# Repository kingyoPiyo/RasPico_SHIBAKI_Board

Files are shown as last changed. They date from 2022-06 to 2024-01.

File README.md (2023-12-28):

# RasPico_SHIBAKI_Board
Raspberry Pi Pico で色々やる基板です。  

### 搭載インタフェース
| インタフェース | 説明 |
| ---- | ---- |
| SFP | 2スロット搭載。TXRX、LOS、TX_FAULT、I2C の基本的な信号線が Pico と接続されています。RATE_SELECT、TX_DISABLE ははんだジャンパで指定します。 |
| GPIO | 2.54mm pitch 2x5ピンヘッダを搭載。4pin + 3.3V + GND が出ています。機能拡張等に使用できます。 |
| LED | 4個搭載（Pico ボードに標準搭載のLEDを含めると合計5個）。Lチカデバッグや UART、S/PDIF 信号を出力して遊べます。 |
| Push SW | User 用2個（プルアップ抵抗付き）、Reset 用1個搭載 |
| SMA Input | 2個搭載。50Ω終端抵抗（標準では未実装）を実装するパッドを用意しています。 |
| SMA Output | 2個搭載。標準で 450Ω の抵抗が直列に挿入されています。50Ω 終端可能なオシロスコープに接続するとx10減衰として機能します。レベルを変更したい場合は適宜抵抗を打ち替えてください。 |

### 基板画像
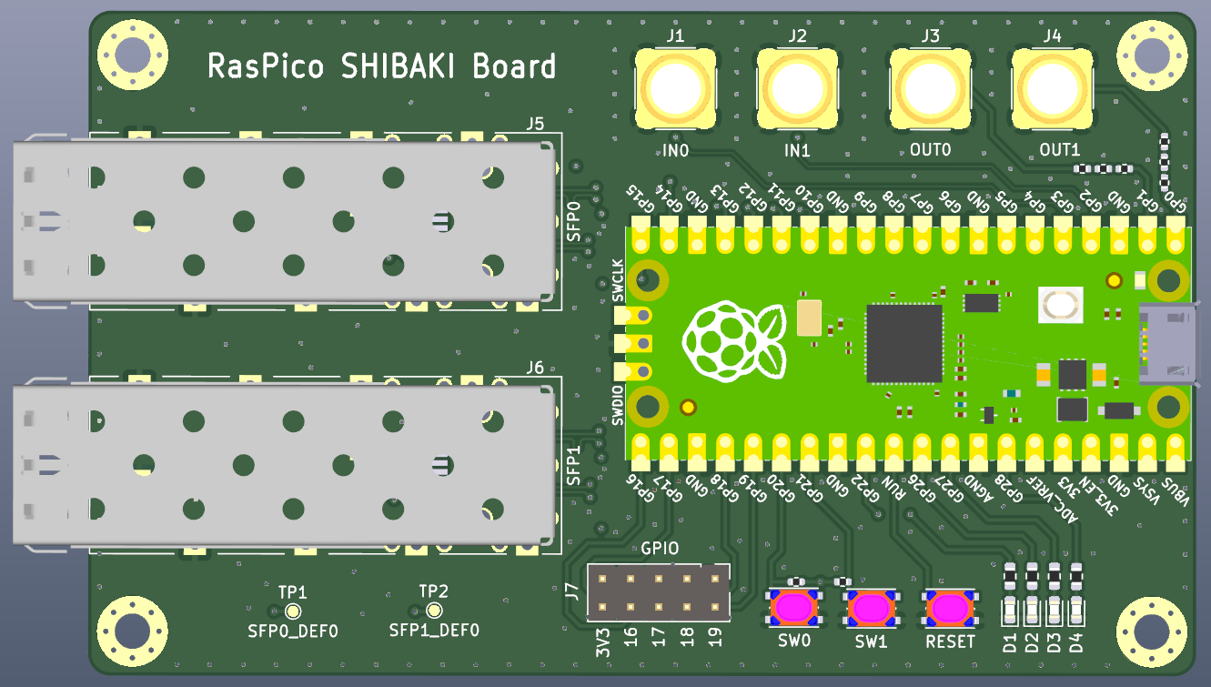
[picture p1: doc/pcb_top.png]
  
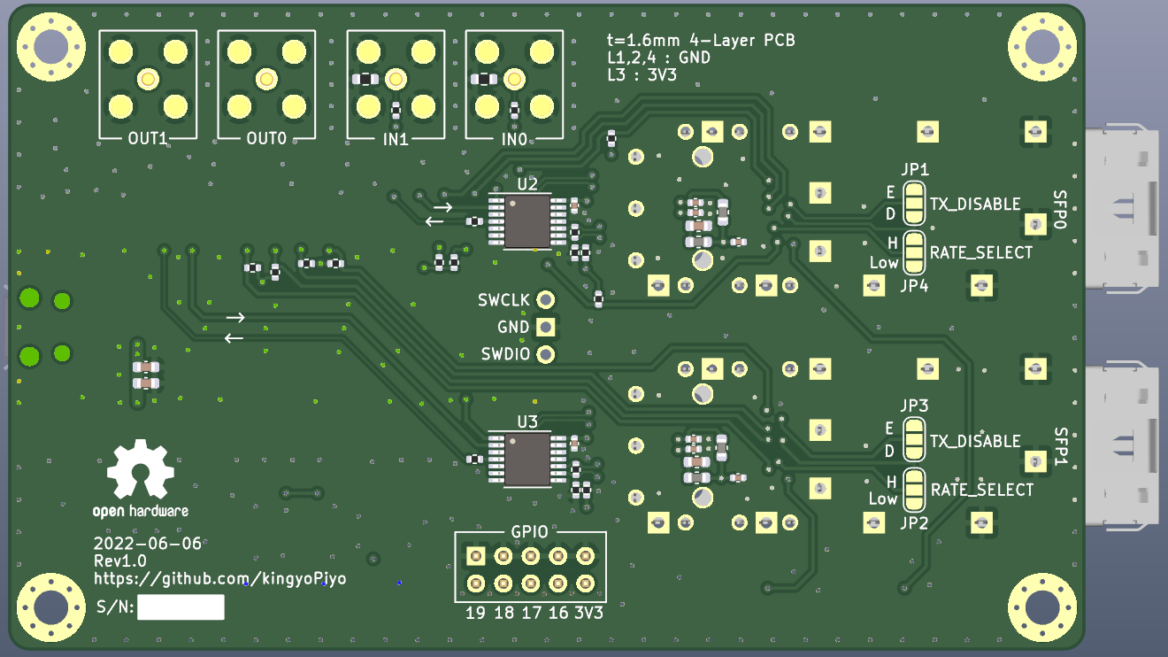
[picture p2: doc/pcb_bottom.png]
  
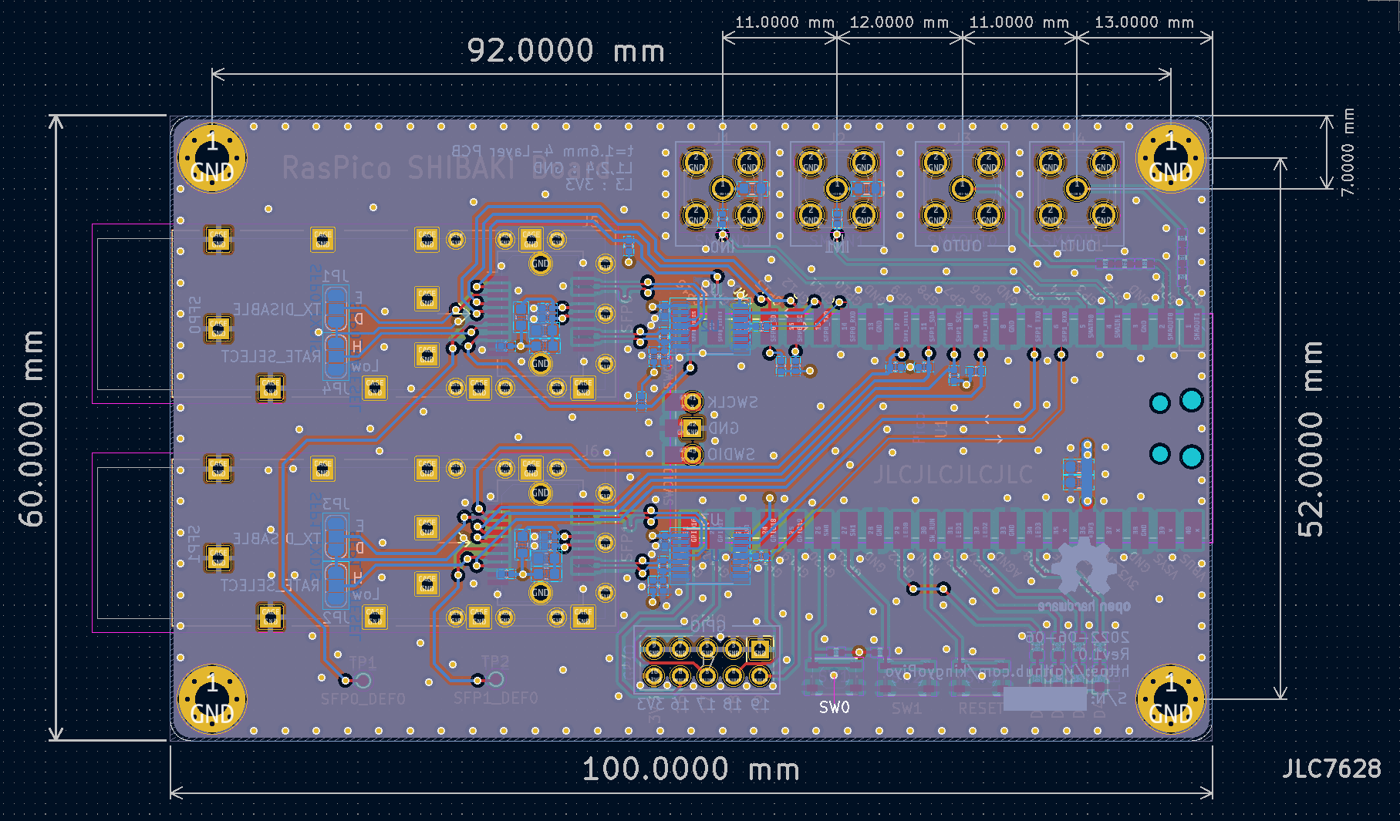
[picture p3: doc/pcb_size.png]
  
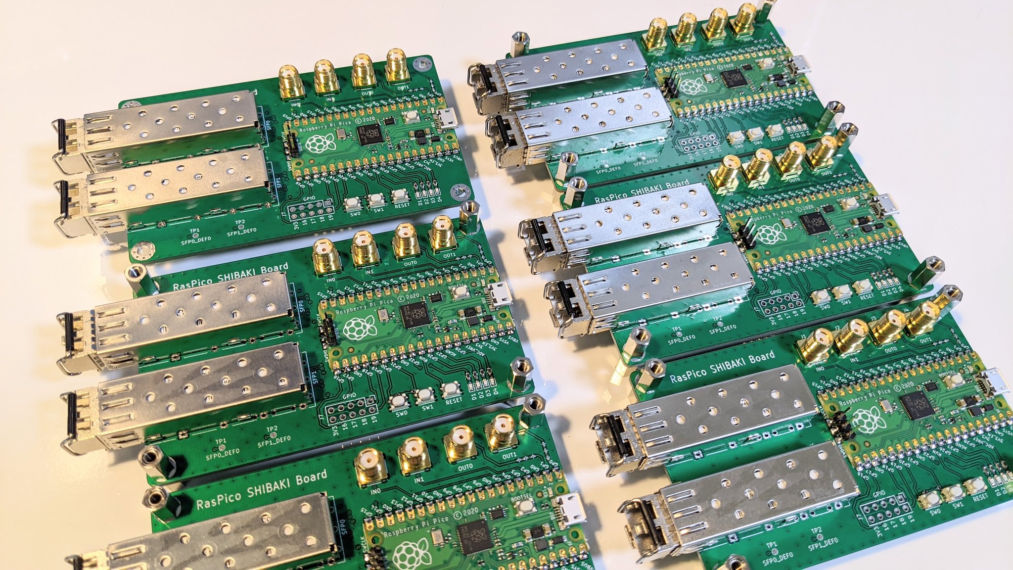
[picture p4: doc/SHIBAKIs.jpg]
  

## サンプルソフトウェア
本ボードで遊べるサンプルプログラムです。  
100BASE-FX による UDP 送信例、VBAN プロトコルによる PCM データ送信、SFP モジュール情報読み出し、8b10b エンコード・デコード（PIO を使った SerDes with Clockrecovery）等を追々追加していく予定です。  
| Link | 説明 |
| ---- | ---- |
| [hwtest](firmware/hwtest/ "hwtest") | ハードウェアテスト用。<br> リセット直後にUSBシリアルから各ピンの電圧レベルやSFPモジュールのI2C読み出しデータ（Addr 0x50）等が出力されます。SW0押下でSFP0ポートからUDPパケットを100BASE-FXでブロードキャストします。SFP1の送受信は実装中... |
| [vban](firmware/vban/ "vban") | RasPico ADC + VBAN Protocol サンプル。<br> GP26(ADC0), GP27(ADC1) からオーディオ信号を入力すると、方チャンネル44.1kHzでサンプリングされてVBANプロトコルに載せてストリーミング送信します。ネットワーク設定はudp.hを適宜書き換えてください。 |
| [pattern_gen](firmware/pattern_gen/ "pattern_gen") | PIOを活用したパターンジェネレータサンプル。<br> SFP0とSMAOUT0端子から125MS/sで位相同期した任意のパターンを出力します。<br> SFPモジュールの伝搬遅延の評価等に使えます。サンプリングクロック周波数や出力端子も任意に設定可能です。 |

## 回路図
[Schematic.pdf](doc/schematic.pdf "Schematic")

## 既知のバグ
[doc/Rev1.0_Jumper.png](doc/Rev1.0_Jumper.png "Rev1.0_Jumper.png") 参照
* SFP0_SCLとSFP0_SDAのピンアサインを入れ替える必要あり
* SFP1_SCLがI2C1_SCLに、SFP1_SDAがI2C0_SDAに割りあたっており、配線修正必要

## 開発環境
- KiCad Version 6.0.5
- Raspberry Pi Pico 3D model and Footprint : [KiCad-RP-Pico](https://github.com/ncarandini/KiCad-RP-Pico "KiCad-RP-Pico")

## pico-sdk install memo
```
sudo apt install cmake gcc-arm-none-eabi libnewlib-arm-none-eabi libstdc++-arm-none-eabi-newlib build-essential
git clone https://github.com/raspberrypi/pico-sdk
cd pico-sdk
git submodule update --init
```

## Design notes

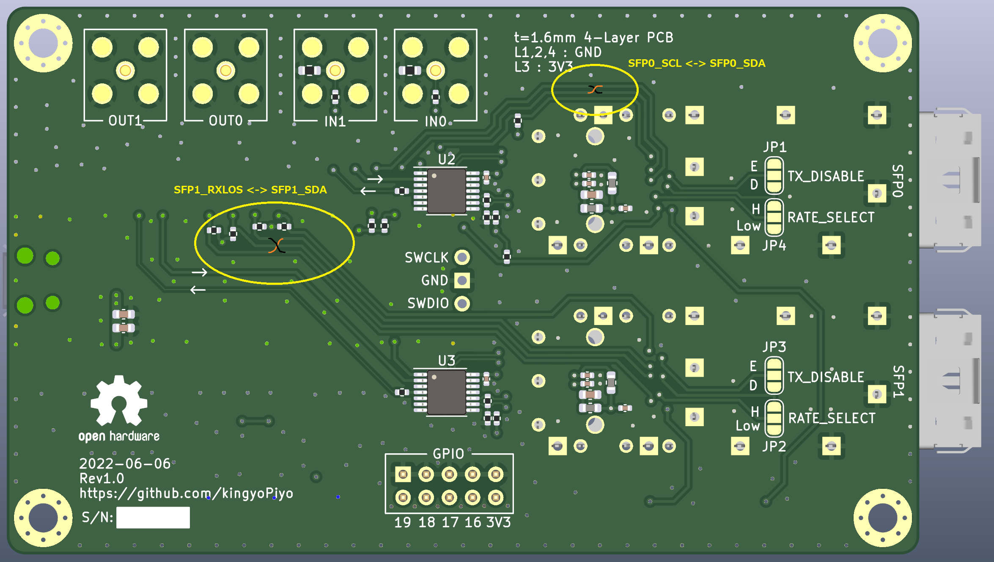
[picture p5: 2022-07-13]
doc/Rev1.0_Jumper.png

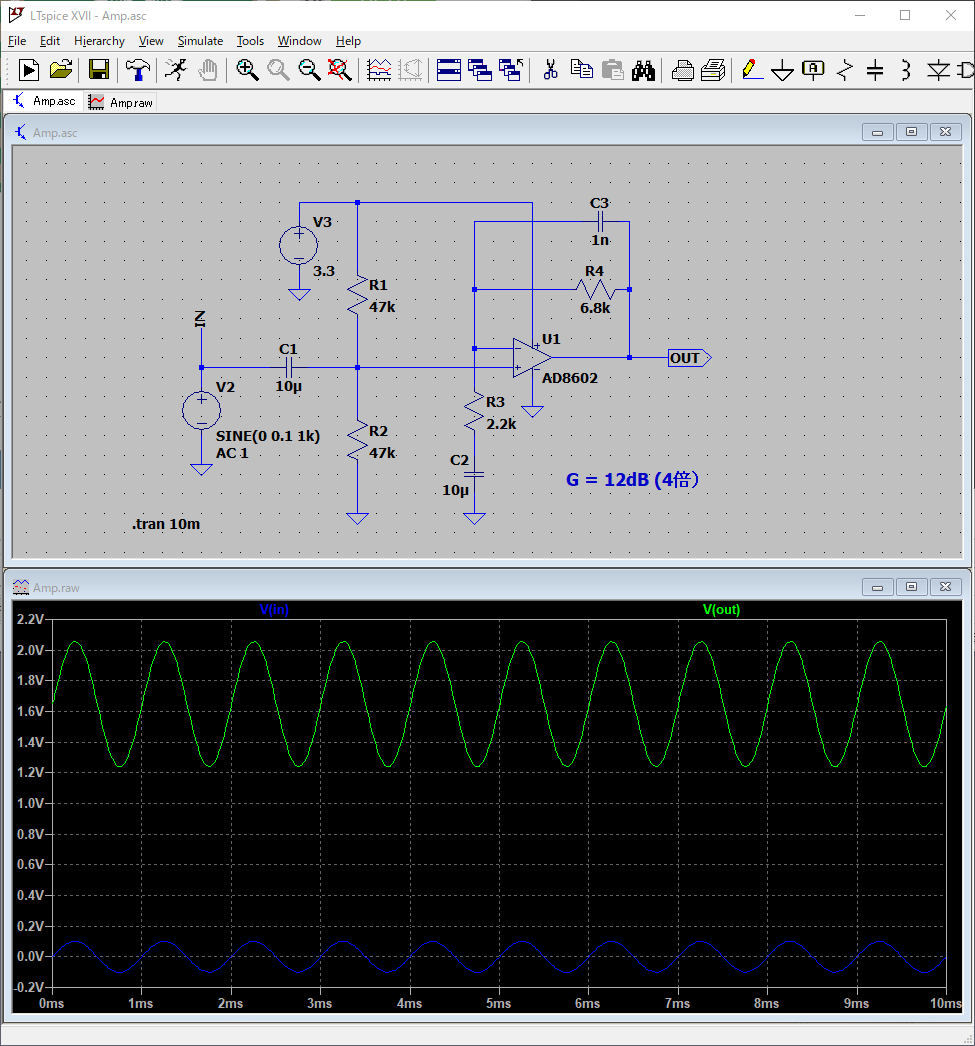
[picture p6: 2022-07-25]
firmware/vban/doc/ADC_PreAmp.png

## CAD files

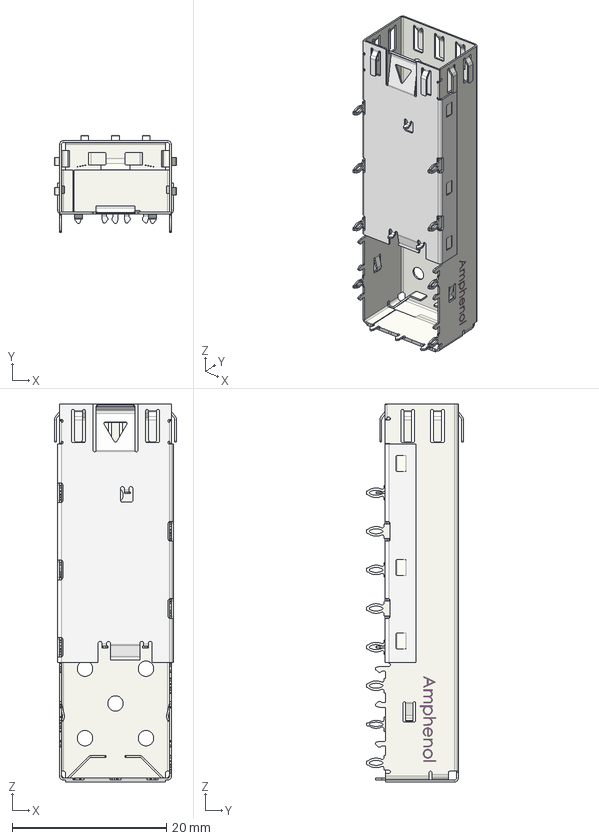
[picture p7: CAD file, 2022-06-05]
KiCad/3D/M-U77-A1118-X00X-REVG5.step
15.8 x 12.6 x 49.0 mm

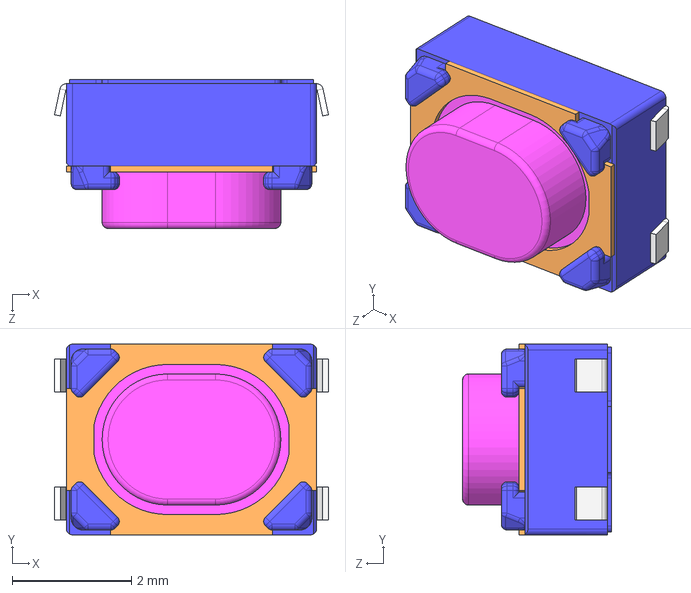
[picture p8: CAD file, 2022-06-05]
KiCad/3D/SKRPAB.STEP
4.60 x 3.20 x 2.50 mm

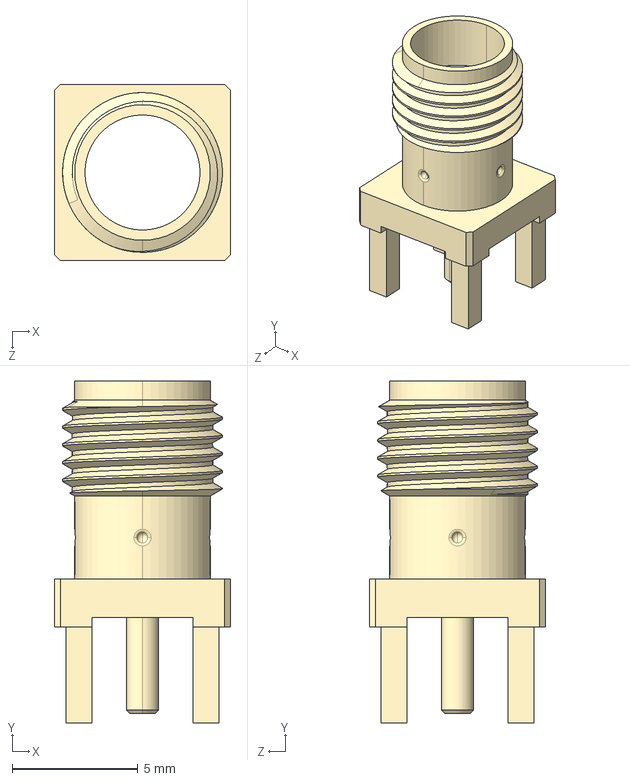
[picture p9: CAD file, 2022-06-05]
KiCad/3D/CONSMA001-G--3DModel-STEP-1.STEP
7.01 x 13.6 x 7.01 mm

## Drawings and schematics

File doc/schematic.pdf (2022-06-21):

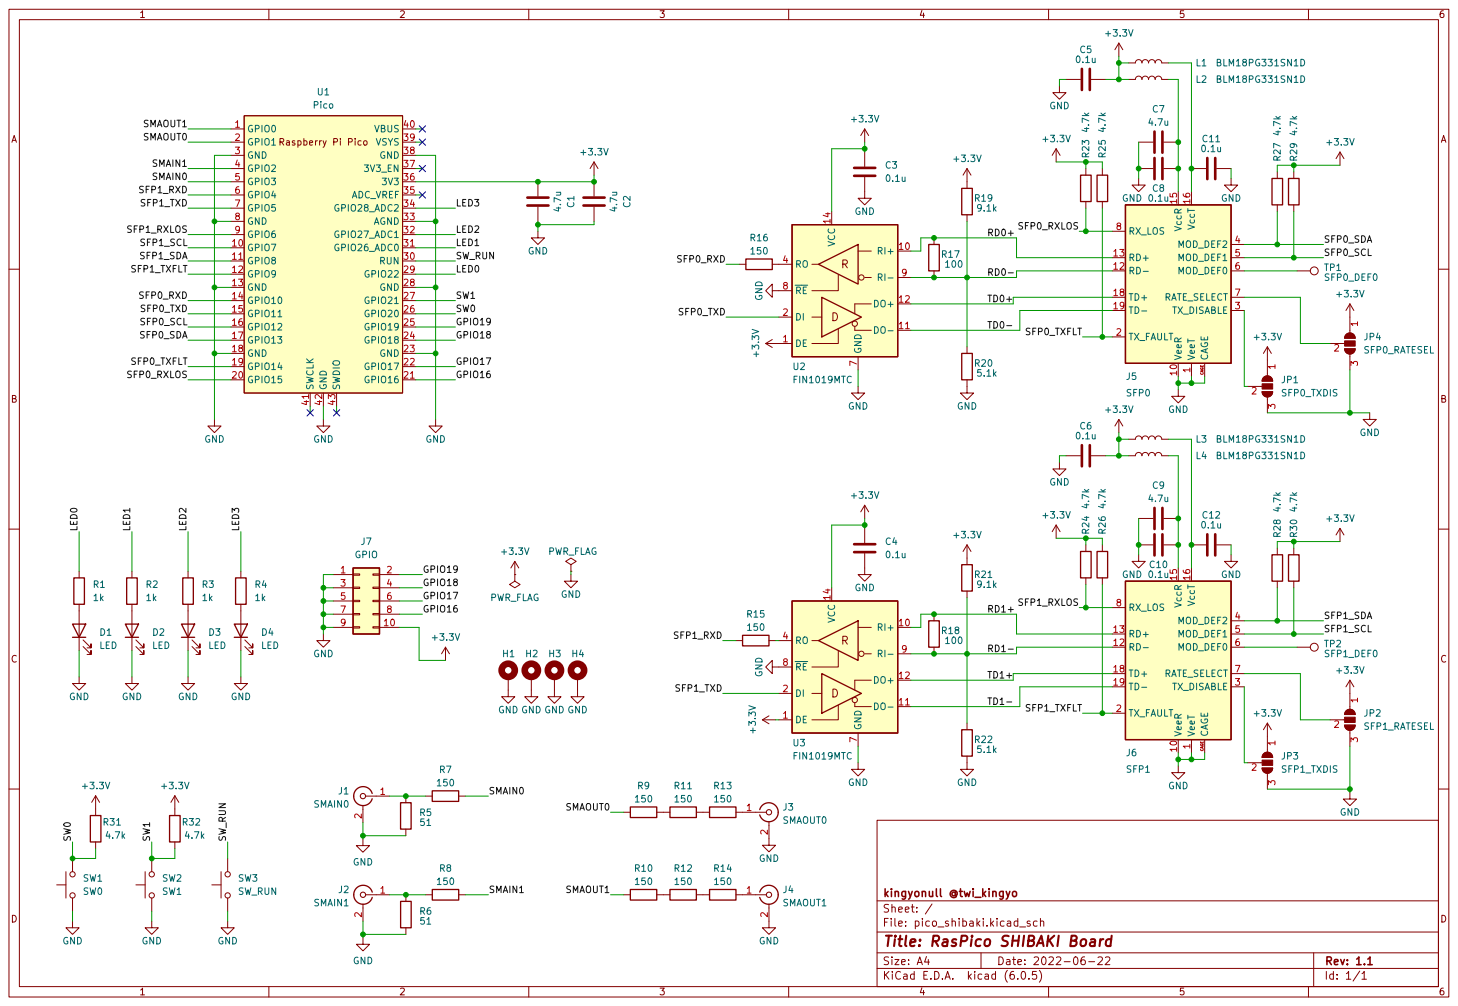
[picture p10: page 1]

1 VeeR 10 RD- 12 RD+ 13 VccR 15 VccT 16 TD+ 18 TD- 19 TX_FAULT 2 TX_DISABLE 3 MOD_DEF2 4 MOD_DEF1 5 MOD_DEF0 6 RATE_SELECT 7 RX_LOS 8 CAGE CAGE J5SFP0 +3.3V GND

7 ~{RE} 8 RI- 9 U2FIN1019MTC GND +3.3V GND VeeT

1 VeeR 10 RD- 12 RD+ 13 VccR 15 VccT 16 TD+ 18 TD- 19 TX_FAULT 2 TX_DISABLE 3 MOD_DEF2 4 MOD_DEF1 5 MOD_DEF0 6 RATE_SELECT 7 RX_LOS 8 CAGE CAGE J6SFP1 +3.3V GND

Id: 1/1 Title: RasPico SHIBAKI Board

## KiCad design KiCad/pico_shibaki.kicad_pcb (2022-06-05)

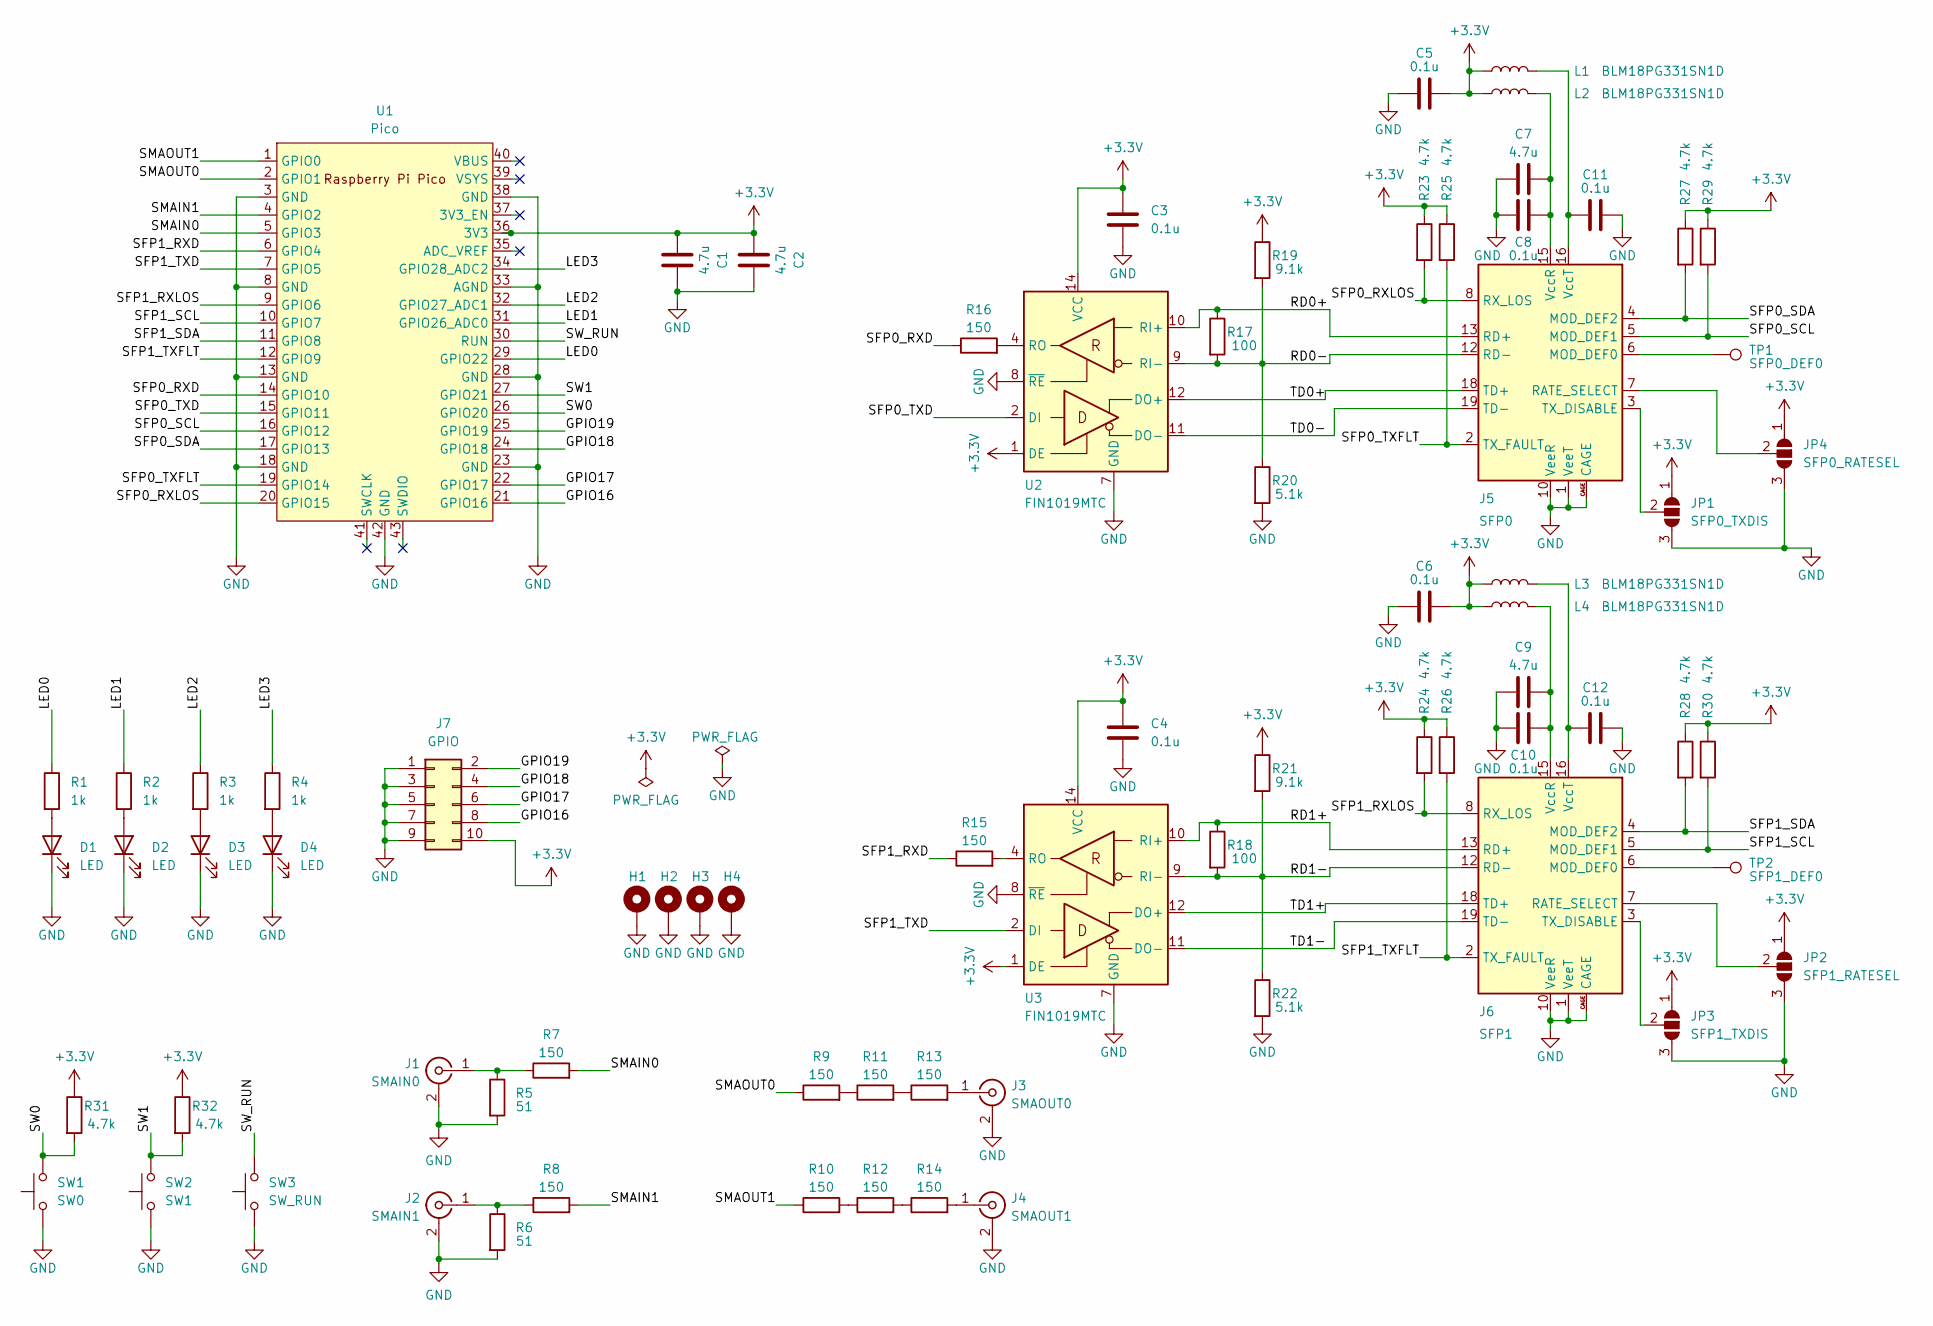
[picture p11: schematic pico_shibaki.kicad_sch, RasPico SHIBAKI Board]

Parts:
C1, C2, C7, C9: 4.7u; C_0603_1608Metric
C3, C4, C5, C6, C8, C10, C11, C12: 0.1u; C_0402_1005Metric
D1, D2, D3, D4: LED; LED_0603_1608Metric
H1, H2, H3, H4: MountingHole_Pad; MountingHole_3.2mm_M3_Pad_Via
J1: SMAIN0; SMA_Amphenol_132134_Vertical
J2: SMAIN1; SMA_Amphenol_132134_Vertical
J3: SMAOUT0; SMA_Amphenol_132134_Vertical
J4: SMAOUT1; SMA_Amphenol_132134_Vertical
J5: SFP0; Connector_SFP_and_Cage
J6: SFP1; Connector_SFP_and_Cage
J7: GPIO; PinHeader_2x05_P2.54mm_Vertical
JP1: SFP0_TXDIS; SolderJumper-3_P1.3mm_Open_RoundedPad1.0x1.5mm_NumberLabels
JP2: SFP1_RATESEL; SolderJumper-3_P1.3mm_Open_RoundedPad1.0x1.5mm_NumberLabels
JP3: SFP1_TXDIS; SolderJumper-3_P1.3mm_Open_RoundedPad1.0x1.5mm_NumberLabels
JP4: SFP0_RATESEL; SolderJumper-3_P1.3mm_Open_RoundedPad1.0x1.5mm_NumberLabels
L1, L2, L3, L4: BLM18PG331SN1D; L_0603_1608Metric
R1, R2, R3, R4: 1k; R_0603_1608Metric
R5, R6: 51; R_0603_1608Metric
R7, R8, R9, R10, R11, R12, R13, R14, R15, R16: 150; R_0402_1005Metric
R17, R18: 100; R_0402_1005Metric
R19, R21: 9.1k; R_0402_1005Metric
R20, R22: 5.1k; R_0402_1005Metric
R23, R24, R25, R26, R27, R28, R29, R30, R31, R32: 4.7k; R_0402_1005Metric
SW1: SW0; SW_Push_1P1T_NO_Vertical_Wuerth_434133025816
SW2: SW1; SW_Push_1P1T_NO_Vertical_Wuerth_434133025816
SW3: SW_RUN; SW_Push_1P1T_NO_Vertical_Wuerth_434133025816
TP1: SFP0_DEF0; TestPoint_Pad_D1.0mm
TP2: SFP1_DEF0; TestPoint_Pad_D1.0mm
U1: Pico; RPi_Pico_SMD_TH
U2, U3: FIN1019MTC; TSSOP-14_4.4x5mm_P0.65mm

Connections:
+3V3: C1.1, C2.1, C3.1, C4.1, C5.2, C6.2, J7.10, JP1.1 (A), JP2.1 (A), JP3.1 (A), JP4.1 (A), L1.1, L2.1, L3.1, L4.1, R19.1, R21.1, R23.1, R24.1, R25.1, R26.1, R27.1, R28.1, R29.1, R30.1, R31.1, R32.1, U1.36 (3V3), U2.1 (DE), U2.14 (VCC), U3.1 (DE), U3.14 (VCC)
/GPIO16: J7.8, U1.21 (GPIO16)
/GPIO17: J7.6, U1.22 (GPIO17)
/GPIO18: J7.4, U1.24 (GPIO18)
/GPIO19: J7.2, U1.25 (GPIO19)
/LED0: R1.1, U1.29 (GPIO22)
/LED1: R2.1, U1.31 (GPIO26_ADC0)
/LED2: R3.1, U1.32 (GPIO27_ADC1)
/LED3: R4.1, U1.34 (GPIO28_ADC2)
/RD0+: J5.13 (RD+), R17.1, U2.10 (RI+)
/RD0-: J5.12 (RD-), R17.2, R19.2, R20.1, U2.9 (RI-)
/RD1+: J6.13 (RD+), R18.1, U3.10 (RI+)
/RD1-: J6.12 (RD-), R18.2, R21.2, R22.1, U3.9 (RI-)
/SFP0_RXD: R16.1, U1.14 (GPIO10)
/SFP0_RXLOS: J5.8 (RX_LOS), R23.2, U1.20 (GPIO15)
/SFP0_SCL: J5.5 (MOD_DEF1), R29.2, U1.16 (GPIO12)
/SFP0_SDA: J5.4 (MOD_DEF2), R27.2, U1.17 (GPIO13)
/SFP0_TXD: U1.15 (GPIO11), U2.2 (DI)
/SFP0_TXFLT: J5.2 (TX_FAULT), R25.2, U1.19 (GPIO14)
/SFP1_RXD: R15.1, U1.6 (GPIO4)
/SFP1_RXLOS: J6.8 (RX_LOS), R24.2, U1.9 (GPIO6)
/SFP1_SCL: J6.5 (MOD_DEF1), R30.2, U1.10 (GPIO7)
/SFP1_SDA: J6.4 (MOD_DEF2), R28.2, U1.11 (GPIO8)
/SFP1_TXD: U1.7 (GPIO5), U3.2 (DI)
/SFP1_TXFLT: J6.2 (TX_FAULT), R26.2, U1.12 (GPIO9)
/SMAIN0: R7.2, U1.5 (GPIO3)
/SMAIN1: R8.2, U1.4 (GPIO2)
/SMAOUT0: R9.1, U1.2 (GPIO1)
/SMAOUT1: R10.1, U1.1 (GPIO0)
/SW0: R31.2, SW1.2, U1.26 (GPIO20)
/SW1: R32.2, SW2.2, U1.27 (GPIO21)
/SW_RUN: SW3.2, U1.30 (RUN)
/TD0+: J5.18 (TD+), U2.12 (DO+)
/TD0-: J5.19 (TD-), U2.11 (DO-)
/TD1+: J6.18 (TD+), U3.12 (DO+)
/TD1-: J6.19 (TD-), U3.11 (DO-)
GND: C1.2, C2.2, C3.2, C4.2, C5.1, C6.1, C7.1, C8.1, C9.1, C10.1, C11.2, C12.2, D1.1 (K), D2.1 (K), D3.1 (K), D4.1 (K), H1.1, H2.1, H3.1, H4.1, J1.2 (Ext), J2.2 (Ext), J3.2 (Ext), J4.2 (Ext), J5.1 (VeeT), J5.9 (VeeR), J5.10 (VeeR), J5.11 (VeeR), J5.14 (VeeR), J5.17 (VeeT), J5.20 (VeeT), J5.CAGE, J6.1 (VeeT), J6.9 (VeeR), J6.10 (VeeR), J6.11 (VeeR), J6.14 (VeeR), J6.17 (VeeT), J6.20 (VeeT), J6.CAGE, J7.1, J7.3, J7.5, J7.7, J7.9, JP1.3 (B), JP2.3 (B), JP3.3 (B), JP4.3 (B), R5.2, R6.2, R20.2, R22.2, SW1.1, SW2.1, SW3.1, U1.3 (GND), U1.8 (GND), U1.13 (GND), U1.18 (GND), U1.23 (GND), U1.28 (GND), U1.33 (AGND), U1.38 (GND), U1.42 (GND), U2.7 (GND), U2.8 (~RE), U3.7 (GND), U3.8 (~RE)
unnamed: C7.2, C8.2, J5.15 (VccR), L2.2
unnamed: C9.2, C10.2, J6.15 (VccR), L4.2
unnamed: C11.1, J5.16 (VccT), L1.2
unnamed: C12.1, J6.16 (VccT), L3.2
unnamed: D1.2 (A), R1.2
unnamed: D2.2 (A), R2.2
unnamed: D3.2 (A), R3.2
unnamed: D4.2 (A), R4.2
unnamed: J1.1 (In), R5.1, R7.1
unnamed: J2.1 (In), R6.1, R8.1
unnamed: J3.1 (In), R13.2
unnamed: J4.1 (In), R14.2
unnamed: J5.3 (TX_DISABLE), JP1.2 (C)
unnamed: J5.6 (MOD_DEF0), TP1.1
unnamed: J5.7 (RATE_SELECT), JP4.2 (C)
unnamed: J6.3 (TX_DISABLE), JP3.2 (C)
unnamed: J6.6 (MOD_DEF0), TP2.1
unnamed: J6.7 (RATE_SELECT), JP2.2 (C)
unnamed: R10.2, R12.1
unnamed: R9.2, R11.1
unnamed: R11.2, R13.1
unnamed: R12.2, R14.1
unnamed: R15.2, U3.4 (RO)
unnamed: R16.2, U2.4 (RO)

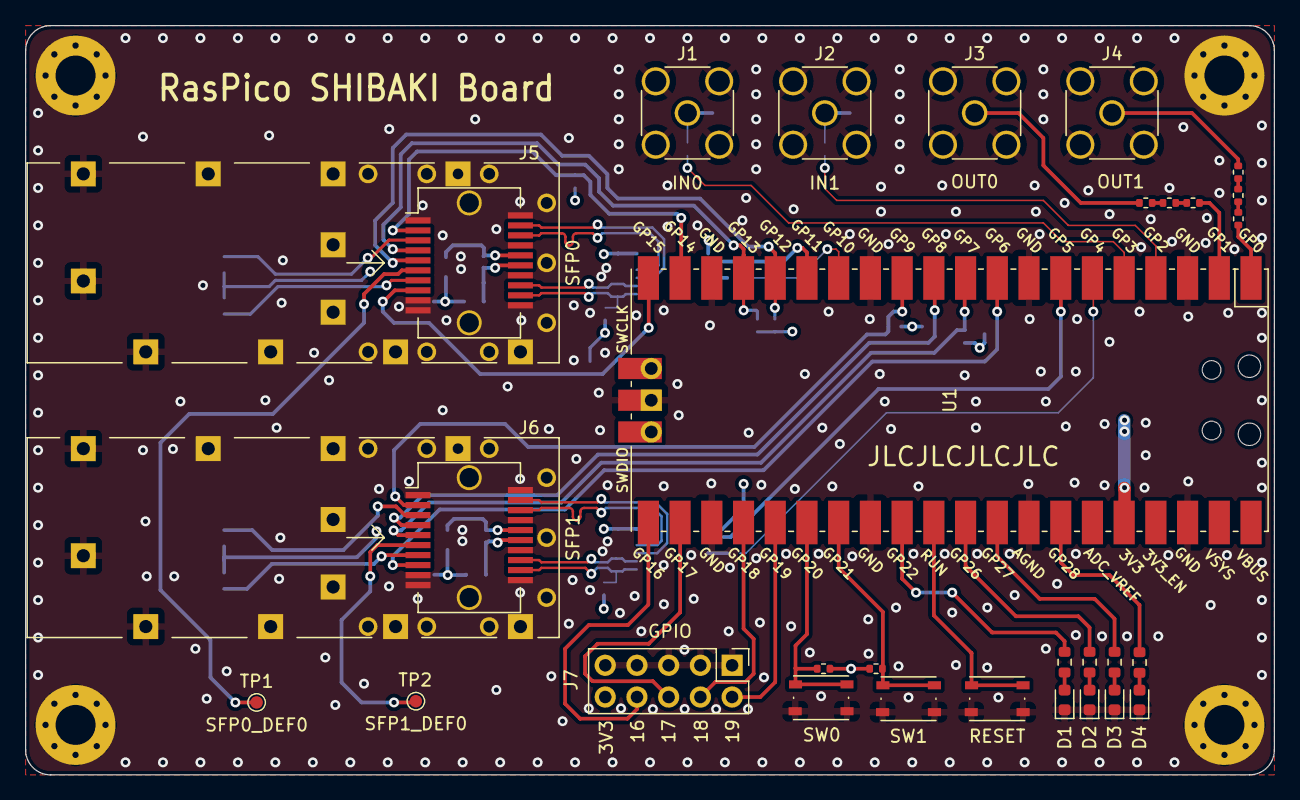
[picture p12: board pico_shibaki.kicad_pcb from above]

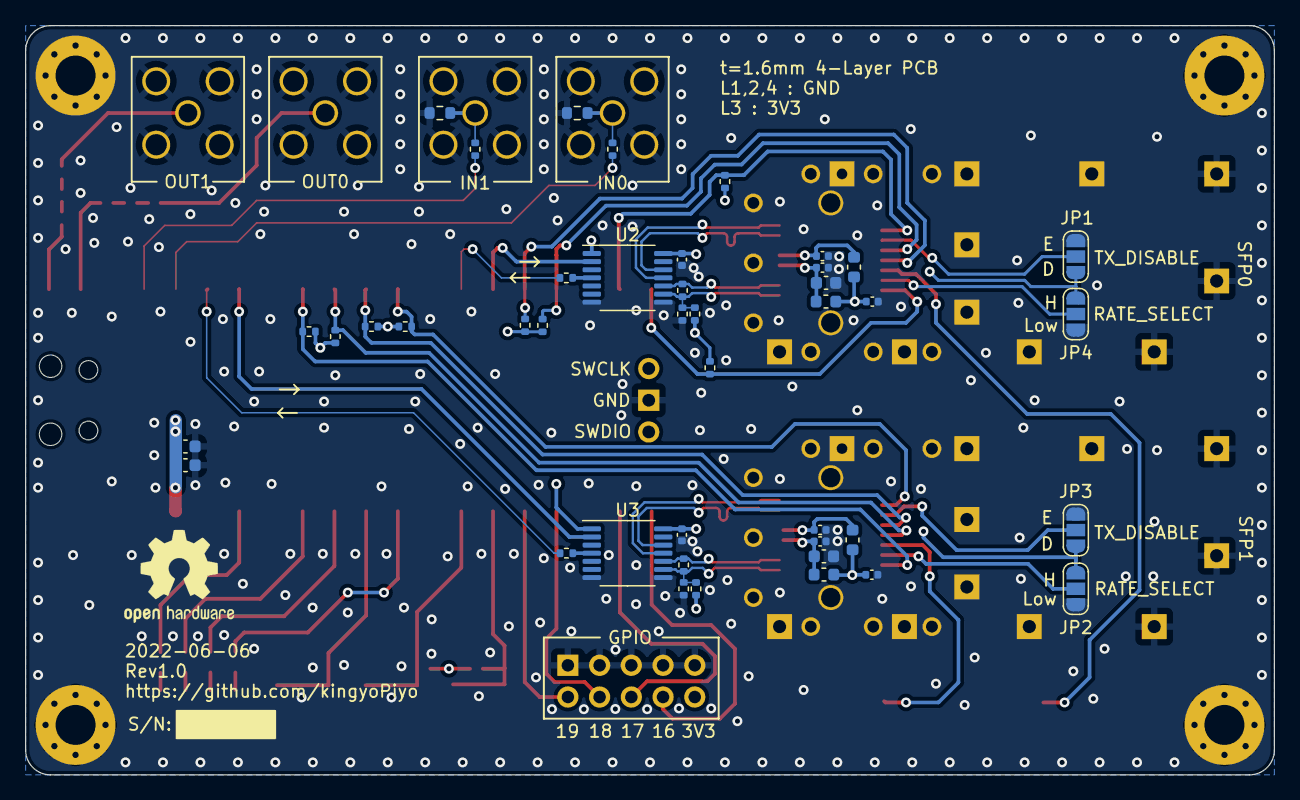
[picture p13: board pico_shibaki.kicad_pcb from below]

Board: 4 copper layers, 100.0 x 60.0 mm, 75 parts (42 on the bottom side), 61 nets.

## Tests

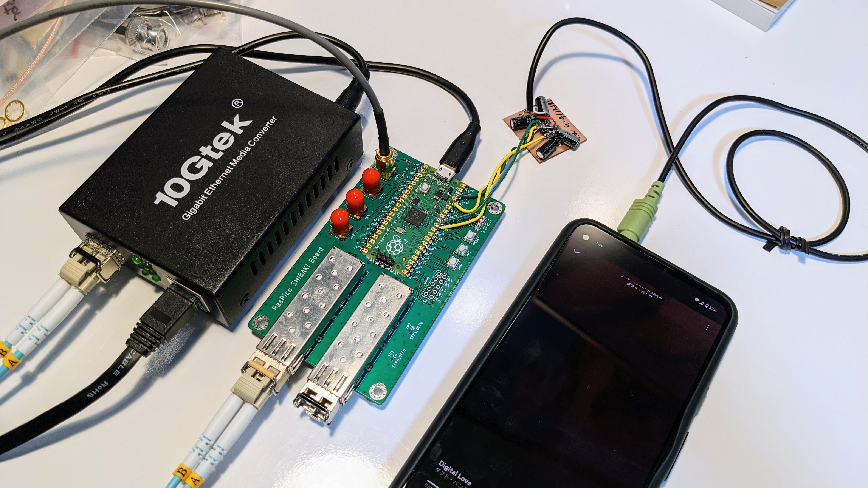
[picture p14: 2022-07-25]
firmware/vban/doc/test_setup.jpg

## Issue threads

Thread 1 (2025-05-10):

Slowest speed for reliable SFP transmission

photon-delight, 2025-05-10:
Hi,

I'd just like to check whether you have tested this board at low speeds.  For example, would it work at 115200 bps?

Thank you

kingyoPiyo, 2025-05-10:
Do you mean you want to transmit 115,200 bps signals (UART?) via optical fiber?
SFP modules can only transmit DC-balanced signals (i.e., digital signals with approximately equal frequencies of 0s and 1s). For example, it is possible to transmit 115,200 bps UART signals using encoding such as 8b10b.

photon-delight, 2025-05-10:
Thank you for the feedback.  Yes, I would like to transmit UART data via optical fiber.  So, if use the 8b10b encoding, I guess I can implement the encoding directly in firmware on the microcontroller.  Have you done anything like this with the RP2040?

kingyoPiyo, 2025-05-11:
Yes, I would like to do it. I understand what you want to do. I have experimented with other projects, but I have used the RP2040 to sample GPIO at 1MHz and perform 8b10b encoding for bi-directional transmission. Please refer to the following link;

https://github.com/htlabnet/RP2040_Universal_SFP_Transceiver

I have not ported it to RasPico_SHIBAKI_Board, but I believe it is relatively easy to run once you understand the code :-)

kingyoPiyo, 2025-05-11:
Glad I could help, the transmission bandwidth on the SFP module side is about 10 Mbps, so you don't need to be that nervous. For differential signals, keeping the paired wires close together will reduce noise radiation and improve signal quality. Also, I like the look of differential wiring, so it is half a hobby :-)
I hope the project goes well !

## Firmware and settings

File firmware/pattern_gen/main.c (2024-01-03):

/********************************************************
* Title    : RasPico SHIBAKI Pattern Generator
* Date     : 2023/12/28
* Note     : 位相同期の取れたテストパターンを出力する
* Design   : kingyo
********************************************************/
#include <stdint.h>
#include "pico/stdlib.h"
#include "hardware/pio.h"
#include "hardware/dma.h"
#include "hw.h"
#include "hwinit.h"
#include "ser_tx.pio.h"

#define DEF_SER_NUM         (2)

// 1Word = 32bit のバッファサイズを指定する
// このバッファの内容をPIOのクロックで途切れなく出力する
// e.g.
//  バッファサイズ = 1000, clk = 125MHz の場合、
//  1000 * 32bit * 8ns = 256us
//  で1Loopとなる
#define DEF_BUF_SIZE        (1000)

int main()
{
    static PIO pio_ser_wr = pio0;
    uint32_t ser_buf[DEF_SER_NUM][DEF_BUF_SIZE] = {0};
    int dma_ch[DEF_SER_NUM];

    stdio_init_all();
    hw_init();
    
    // PIO init
    uint offset = pio_add_program(pio_ser_wr, &ser_tx_program);
    ser_tx_program_init(pio_ser_wr, 0, offset, HW_PINNUM_SFP0_TXD);     // SFP0
    ser_tx_program_init(pio_ser_wr, 1, offset, HW_PINNUM_SMAOUT0);      // SMA0

    // DMA channel setting
    for (int i = 0; i < DEF_SER_NUM; i++) {
        dma_ch[i] = dma_claim_unused_channel(true);
        dma_channel_config c0 = dma_channel_get_default_config(dma_ch[i]);
        channel_config_set_dreq(&c0, pio_get_dreq(pio_ser_wr, i, true));
        channel_config_set_transfer_data_size(&c0, DMA_SIZE_32);
        channel_config_set_read_increment(&c0, true);
        channel_config_set_write_increment(&c0, false);

        dma_channel_configure (
            dma_ch[i],              // Channel to be configured
            &c0,                    // The configuration we just created
            &pio_ser_wr->txf[i],    // Destination address
            ser_buf[i],             // Source address
            DEF_BUF_SIZE,           // Number of transfers
            false                   // Don't start yet
        );
    }


    // パターンデータの生成
    // データは右シフト（LSBから送信）で送出
    for (int i = 0; i < DEF_BUF_SIZE; i++) {
        ser_buf[0][i] = 0x55555555;
    }
    ser_buf[0][DEF_BUF_SIZE-1] = 0x0F555555;

    for (int i = 0; i < DEF_BUF_SIZE; i++) {
        ser_buf[1][i] = 0x00000000;
    }
    ser_buf[1][DEF_BUF_SIZE-1] = 0x0F000000;

    
    // 初回の転送開始位相を揃えるための時間稼ぎとして、
    // TX_FIFO 8Word分をゼロ埋めしておく
    for (int i = 0; i < 8; i++) {
        for (int sm = 0; sm < DEF_SER_NUM; sm++) {
            pio_sm_put_blocking(pio_ser_wr, sm, 0);
        }
    }


    // SMを同期して起動
    pio_enable_sm_mask_in_sync(pio_ser_wr, 0b11);

    // 動作表示
    gpio_put(HW_PINNUM_LED0, true);

    // ser_bufを途切れなく連続転送する
    while (true) {
        // DMA Readアドレス再設定
        dma_channel_set_read_addr(dma_ch[0], ser_buf[0], true);
        dma_channel_set_read_addr(dma_ch[1], ser_buf[1], true);
        
        // DMA転送完了待ち
        dma_channel_wait_for_finish_blocking(dma_ch[0]);
        dma_channel_wait_for_finish_blocking(dma_ch[1]);
    }
}

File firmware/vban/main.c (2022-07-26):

/********************************************************
* Title    : RasPico SHIBAKI VBAN Sample
* Date     : 2022/07/25
* Note     : GP26 -- Audio L-ch
             GP27 -- Audio R-ch
* Design   : kingyo
********************************************************/
#include "pico/stdlib.h"
#include "hardware/irq.h"
#include "hw.h"
#include "hwinit.h"
#include "vban.h"

static struct repeating_timer timer;

// Timer interrupt (L-tika)
static bool repeating_timer_callback(struct repeating_timer *t)
{
    static bool led0_state = true;

    gpio_put(HW_PINNUM_LED0, led0_state);
    led0_state = !led0_state;

    return true;
}


int main()
{
    stdio_init_all();
    hw_init();
    
    // L-tika ~~
    add_repeating_timer_ms(-500, repeating_timer_callback, NULL, &timer);

    vban_init();
    while (true)
    {
        vban_main();
    }
}

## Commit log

2022-06-05 Add KiCad project files
    [CONSMA001-G--3DModel-STEP-1.STEP, M-U77-A1118-X00X-REVG5.step, SKRPAB.STEP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]
2022-07-12 Add UART debug message "forever mode"
2022-07-13 i2c pinout bug....
2022-07-13 Add SFP I2C EEPROM Read
2022-07-19 Add Pico onboard LED!!
2022-07-24 Add VBAN Sample.
2022-07-25 DCDC is PWM mode....
2023-01-05 Accelerated using DMA
2023-12-28 Add Pattern Generator sample.
2023-12-28 動作表示追加
2023-12-28 Warning対策
2023-12-28 プロジェクト名変更&RAM展開有効化
2023-12-28 プロジェクト名変更
